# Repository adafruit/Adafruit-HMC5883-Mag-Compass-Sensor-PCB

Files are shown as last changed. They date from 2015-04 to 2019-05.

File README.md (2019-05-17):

# Adafruit HMC5883 Magnetic Compass Sensor PCB (Discontinued)
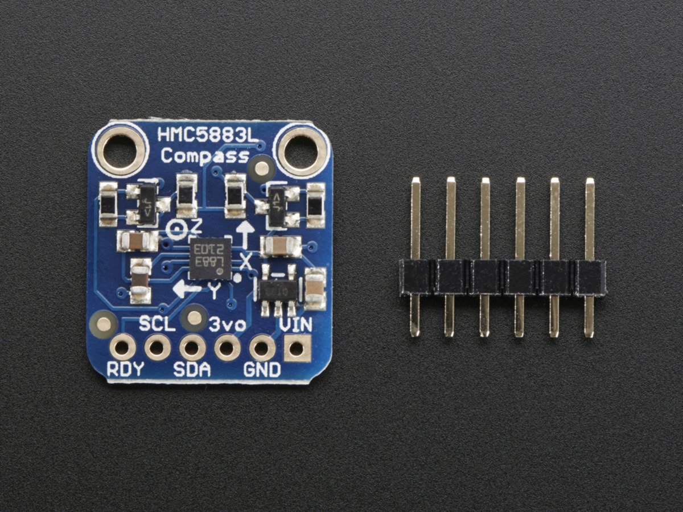
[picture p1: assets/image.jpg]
<a href="http://www.adafruit.com/products/1746"><br/>
Click here to review the Adafruit shop</a>

We based this breakout on a popular and well loved magnetometer, the HMC5883L. This compact sensor uses I2C to communicate and its very easy to use. Since it's a 3.3V max chip, we added circuitry to make it 5V-safe logic and power, for easy use with either 3 or 5V microcontrollers. Simply connect VCC to +3-5V and ground to ground. Then read data from the I2C clock and data pins. There's also a Data Ready pin you can use to speed up reads.

PCB files for Adafruit HMC5883 Mag Compass Sensor PCB. The format is EagleCAD schematic and board layout
- https://www.adafruit.com/products/1746

### License

Adafruit invests time and resources providing this open source design, please support Adafruit and open-source hardware by purchasing products from [Adafruit](https://www.adafruit.com)!

All text above must be included in any redistribution

Designed by Limor Fried/Ladyada for Adafruit Industries.
Creative Commons Attribution/Share-Alike, all text above must be included in any redistribution. 
See license.txt for additional information.

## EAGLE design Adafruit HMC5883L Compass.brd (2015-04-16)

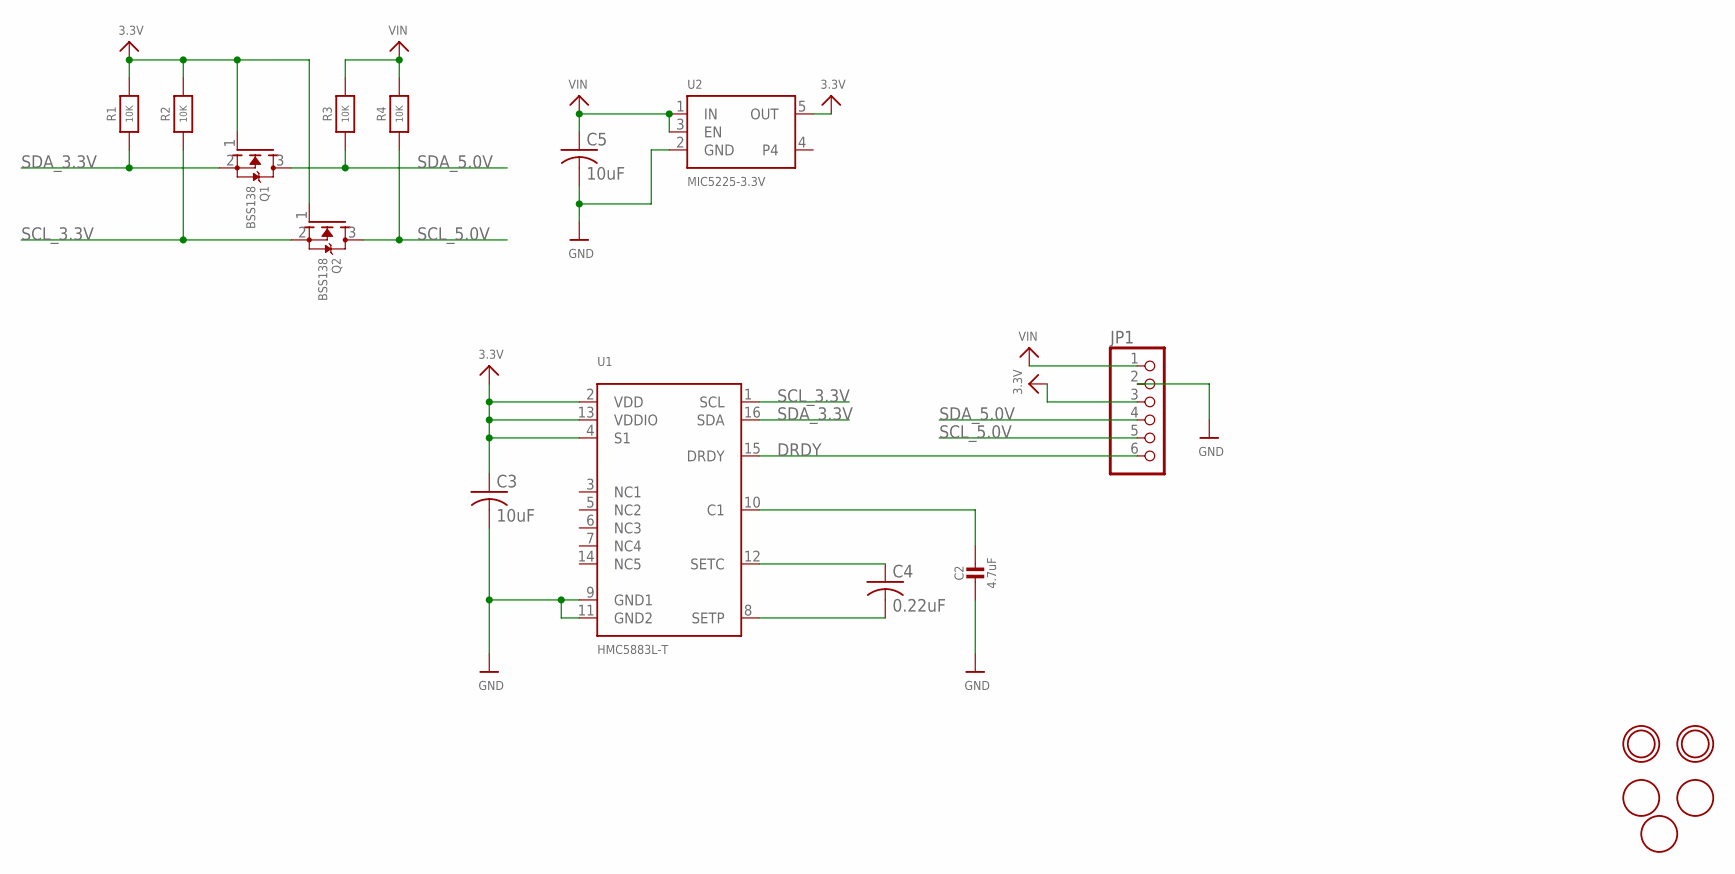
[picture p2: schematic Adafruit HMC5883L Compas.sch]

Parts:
C2: 4.7uF; 0805_10MGAP
C3, C5: 10uF; C0805
C4: 0.22uF; C0805
JP1: HEADER-1X676MIL; 1X06_ROUND_76
Q1, Q2: BSS138; SOT23-WIDE
R1, R2: 10K; _0805MP
R3, R4: 10K; 0805-NO
U1: HMC5883L-T; HMC5883L
U2: MIC5225-3.3V; SOT23-5
U$8, U$9: MOUNTINGHOLE2.5; MOUNTINGHOLE_2.5_PLATED
U$10, U$11, U$12: FIDUCIAL; FIDUCIAL_1MM

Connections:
3.3V: C3.1, JP1.3, Q1.1 (G), Q2.1 (G), R1.2, R2.2, U1.2 (VDD), U1.4 (S1), U1.13 (VDDIO), U2.5 (OUT)
DRDY: JP1.6, U1.15 (DRDY)
GND: C2.2, C3.2, C5.2, JP1.2, U1.9 (GND1), U1.11 (GND2), U2.2 (GND)
unnamed: C4.1, U1.12 (SETC)
unnamed: C4.2, U1.8 (SETP)
unnamed: C2.1, U1.10 (C1)
SCL_3.3V: Q2.2 (S), R2.1, U1.1 (SCL)
SCL_5.0V: JP1.5, Q2.3 (D), R4.1
SDA_3.3V: Q1.2 (S), R1.1, U1.16 (SDA)
SDA_5.0V: JP1.4, Q1.3 (D), R3.1
VIN: C5.1, JP1.1, R3.2, R4.2, U2.1 (IN), U2.3 (EN)

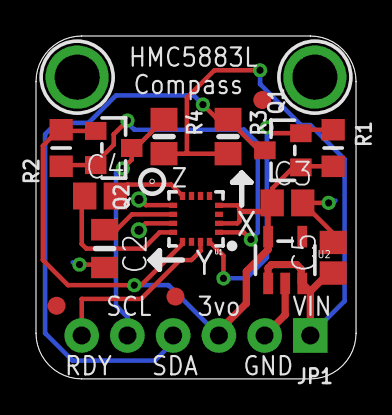
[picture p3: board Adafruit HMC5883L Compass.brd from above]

Board: 2 copper layers, 17.8 x 19.1 mm, 19 parts (1 on the bottom side), 11 nets.

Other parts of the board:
U$7: ADAFRUIT_5MM
